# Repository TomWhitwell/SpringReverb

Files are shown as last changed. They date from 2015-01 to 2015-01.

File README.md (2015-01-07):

# Music Thing Spring Reverb  

This repository contains PCB files for the Music Thing Spring Reverb project.  

Full documentation at [Music Thing Modular](http://musicthing.co.uk/modular/?page_id=579)  

Please [report any issues in the Issue Log](https://github.com/TomWhitwell/SpringReverb/issues)

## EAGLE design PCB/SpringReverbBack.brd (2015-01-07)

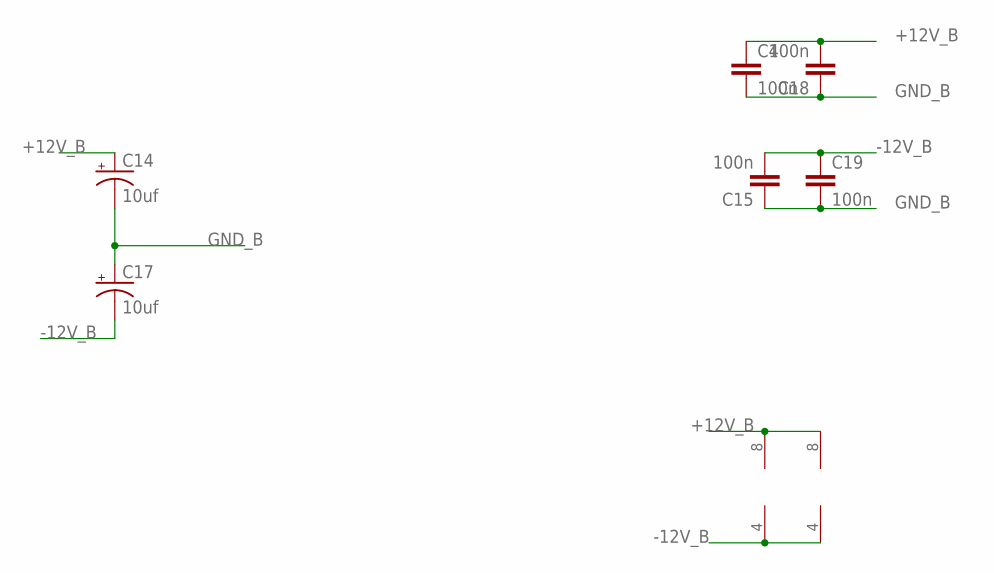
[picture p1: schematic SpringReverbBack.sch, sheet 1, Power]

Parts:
BRICK: TL072; DIL08
C4, C15, C18, C19: 100n; C050-024X044
C14, C17: 10uf; CPOL-RADIAL-10UF-25V
IC4_DRV_RCVR: TL072; DIL08

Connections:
+12V_B: BRICK.8 (V+), C4.1, C14.1 (+), C18.2, IC4_DRV_RCVR.8 (V+); also elsewhere on the board
-12V_B: BRICK.4 (V-), C15.2, C17.2 (-), C19.1, IC4_DRV_RCVR.4 (V-); also elsewhere on the board
GND_B: C4.2, C14.2 (-), C15.1, C17.1 (+), C18.1, C19.2; also elsewhere on the board

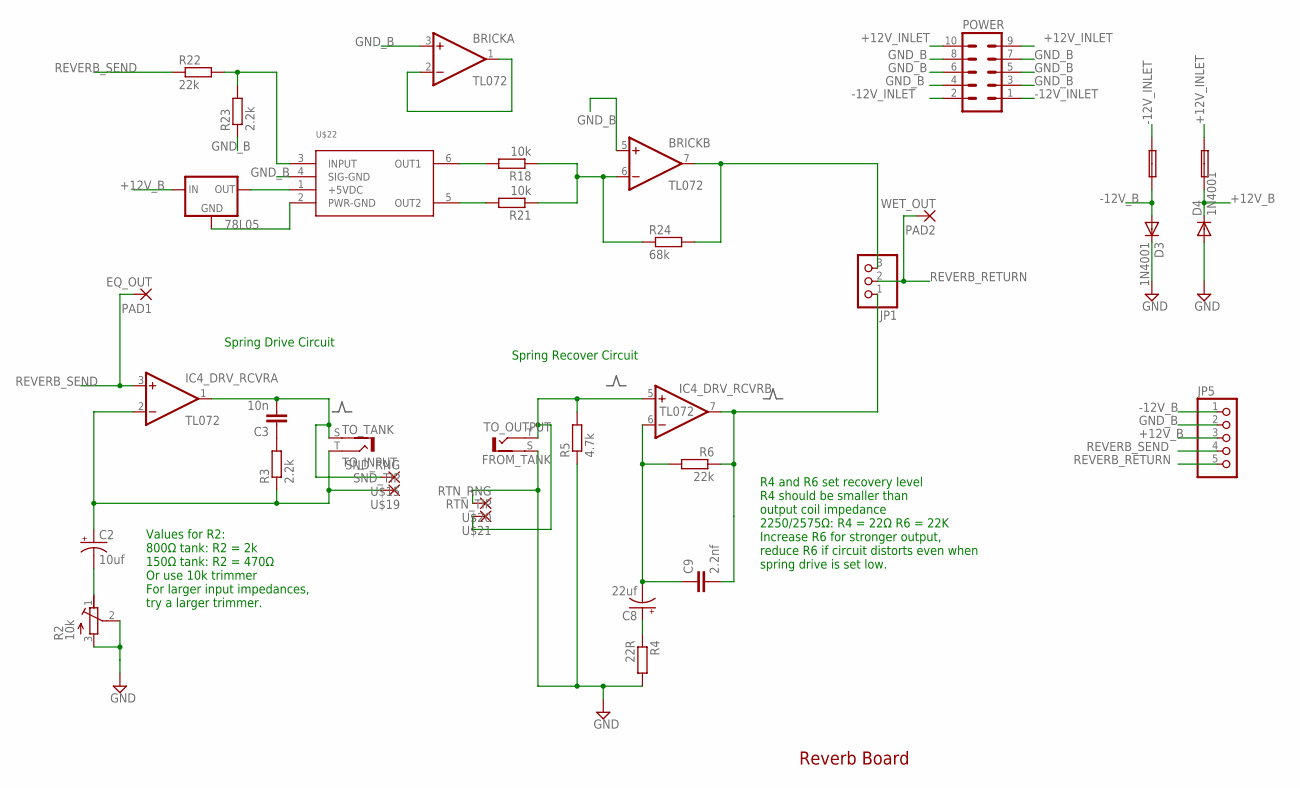
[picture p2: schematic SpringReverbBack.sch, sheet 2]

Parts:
0.1A_FUSE, 0.1A_FUSE_2: FUSE; C050H075X075
78L05: V_REG_78XXTO-92; TO-92
BRICK: TL072; DIL08
C2: 10uf; CPOL-RADIAL-10UF-25V
C3: 10n; C050-024X044
C8: 22uf; CPOL-RADIAL-10UF-25V
C9: 2.2nf; C050-024X044
D3, D4: 1N4001; DO41-10
IC4_DRV_RCVR: TL072; DIL08
JP1: PINHD-1X3; 1X03
JP5: PINHD-1X5; 1X05
PAD1: EQ_OUT; LONG_PAD_1
PAD2: WET_OUT; LONG_PAD_1
POWER: 10_PIN_HEADER; MA05-2
R2: 10k; RTRIMT93YA
R3, R23: 2.2k; 0207/10
R4: 22R; 0207/10
R5: 4.7k; 0207/10
R6, R22: 22k; 0207/10
R18, R21: 10k; 0207/10
R24: 68k; 0207/10
TO_INPUT: TO_TANK; BTOR1
TO_OUTPUT: FROM_TANK; BTOR1
U$15: SND_RNG; LONG_PAD_1
U$19: SND_TIP; LONG_PAD_1
U$20: RTN_RNG; LONG_PAD_1
U$21: RTN_TIP; LONG_PAD_1
U$22: BTDR-2H

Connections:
+12V_B: 0.1A_FUSE_2.1, 78L05.3 (IN), D4.C, JP5.3; also elsewhere on the board
+12V_INLET: 0.1A_FUSE_2.2, POWER.9, POWER.10
-12V_B: 0.1A_FUSE.1, D3.A, JP5.1; also elsewhere on the board
-12V_INLET: 0.1A_FUSE.2, POWER.1, POWER.2
GND_B: BRICK.3 (+IN), BRICK.5 (+IN), D3.C, D4.A, JP5.2, POWER.3, POWER.4, POWER.5, POWER.6, POWER.7, POWER.8, R2.2 (S), R2.3 (E), R4.2, R5.1, R23.1, TO_OUTPUT.S (2), U$20.P$1, U$22.4 (SIG-GND); also elsewhere on the board
unnamed: C2.2 (-), R2.1 (A)
unnamed: C3.1, R3.2
unnamed: C3.2, IC4_DRV_RCVR.1 (OUT), TO_INPUT.S (2), U$15.P$1
unnamed: C2.1 (+), IC4_DRV_RCVR.2 (-IN), R3.1, TO_INPUT.T (1), U$19.P$1
unnamed: IC4_DRV_RCVR.5 (+IN), R5.2, TO_OUTPUT.T (1), U$21.P$1
unnamed: C8.1 (+), R4.1
unnamed: C8.2 (-), C9.1, IC4_DRV_RCVR.6 (-IN), R6.2
unnamed: 78L05.1 (OUT), U$22.1 (+5VDC)
unnamed: R22.2, R23.2, U$22.3 (INPUT)
unnamed: R18.2, U$22.6 (OUT1)
unnamed: R21.2, U$22.5 (OUT2)
unnamed: BRICK.6 (-IN), R18.1, R21.1, R24.1
unnamed: 78L05.2 (GND), U$22.2 (PWR-GND)
unnamed: BRICK.1 (OUT), BRICK.2 (-IN)
unnamed: BRICK.7 (OUT), JP1.3, R24.2
unnamed: C9.2, IC4_DRV_RCVR.7 (OUT), JP1.1, R6.1
REVERB_RETURN: JP1.2, JP5.5, PAD2.P$1
REVERB_SEND: IC4_DRV_RCVR.3 (+IN), JP5.4, PAD1.P$1, R22.1

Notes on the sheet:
Values for R2: 800Ω tank: R2 = 2k 150Ω tank: R2 = 470Ω Or use 10k trimmer For larger input impedances, try a larger trimmer.
Spring Drive Circuit
R4 and R6 set recovery level R4 should be smaller than output coil impedance 2250/2575Ω: R4 = 22Ω R6 = 22K Increase R6 for stronger output, reduce R6 if circuit distorts even when spring drive is set low.
Spring Recover Circuit
Reverb Board

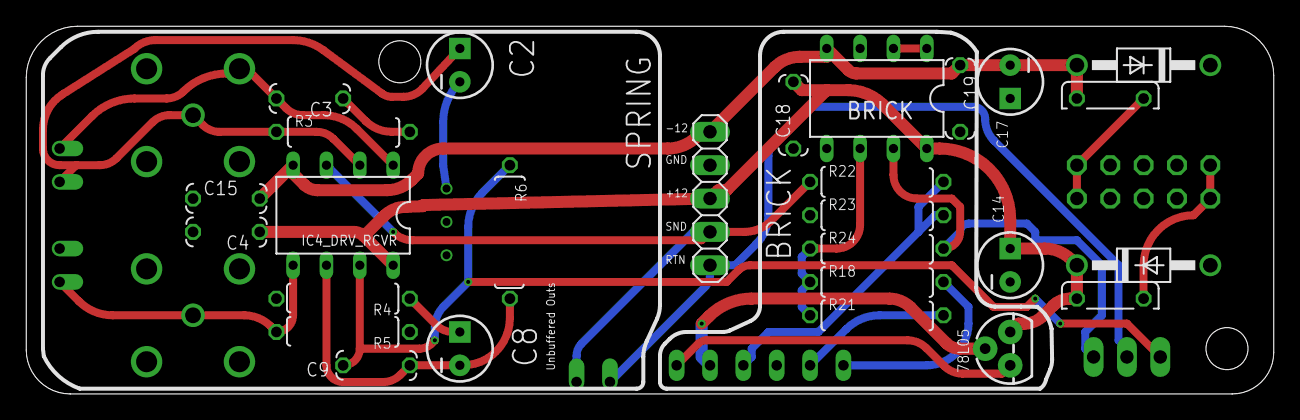
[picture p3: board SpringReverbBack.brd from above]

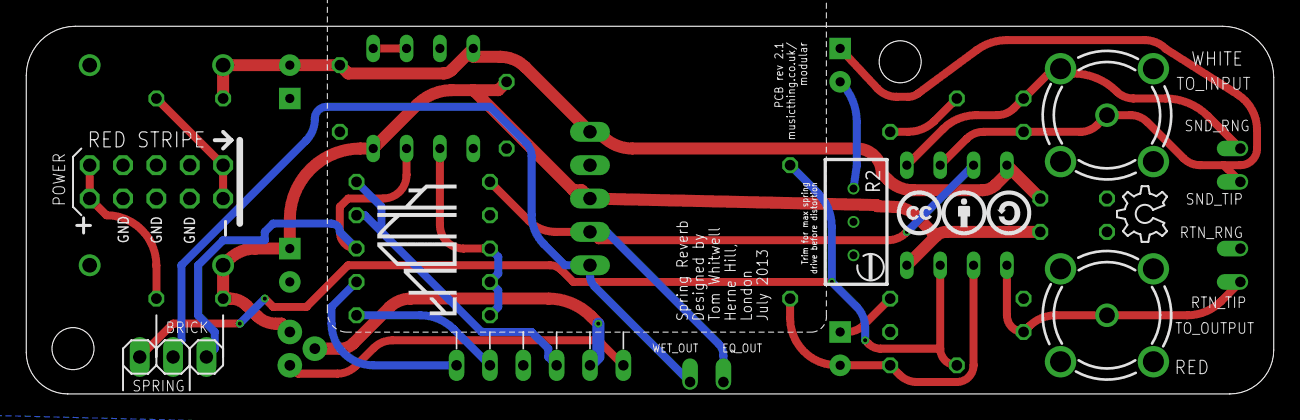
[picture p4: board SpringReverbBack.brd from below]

Board: 4 copper layers, 95.0 x 28.0 mm, 43 parts (10 on the bottom side), 23 nets.

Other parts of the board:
U$1: CC_1CM_SCREENPRINT
U$2: MTM_1CM_KEEPOUT
U$3: OSHW_6X150_NOTEXT
U$4: THONK_1CM_SCREENPRINT

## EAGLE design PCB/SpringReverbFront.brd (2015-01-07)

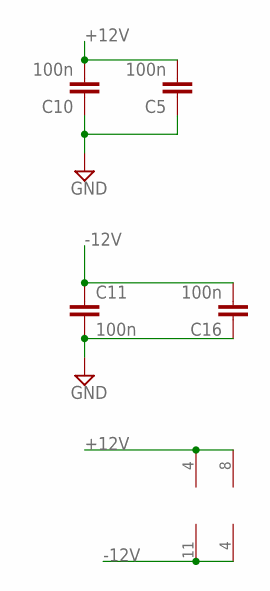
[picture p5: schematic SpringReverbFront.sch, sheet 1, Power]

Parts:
C5, C10, C11, C16: 100n; C050-024X044
IC1: TL074; DIL14
IC2_EQ: NE5532; DIL08

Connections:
+12V: C5.2, C10.2, IC1.4 (V+), IC2_EQ.8 (V+); also elsewhere on the board
-12V: C11.1, C16.2, IC1.11 (V-), IC2_EQ.4 (V-); also elsewhere on the board
GND: C5.1, C10.1, C11.2, C16.1; also elsewhere on the board

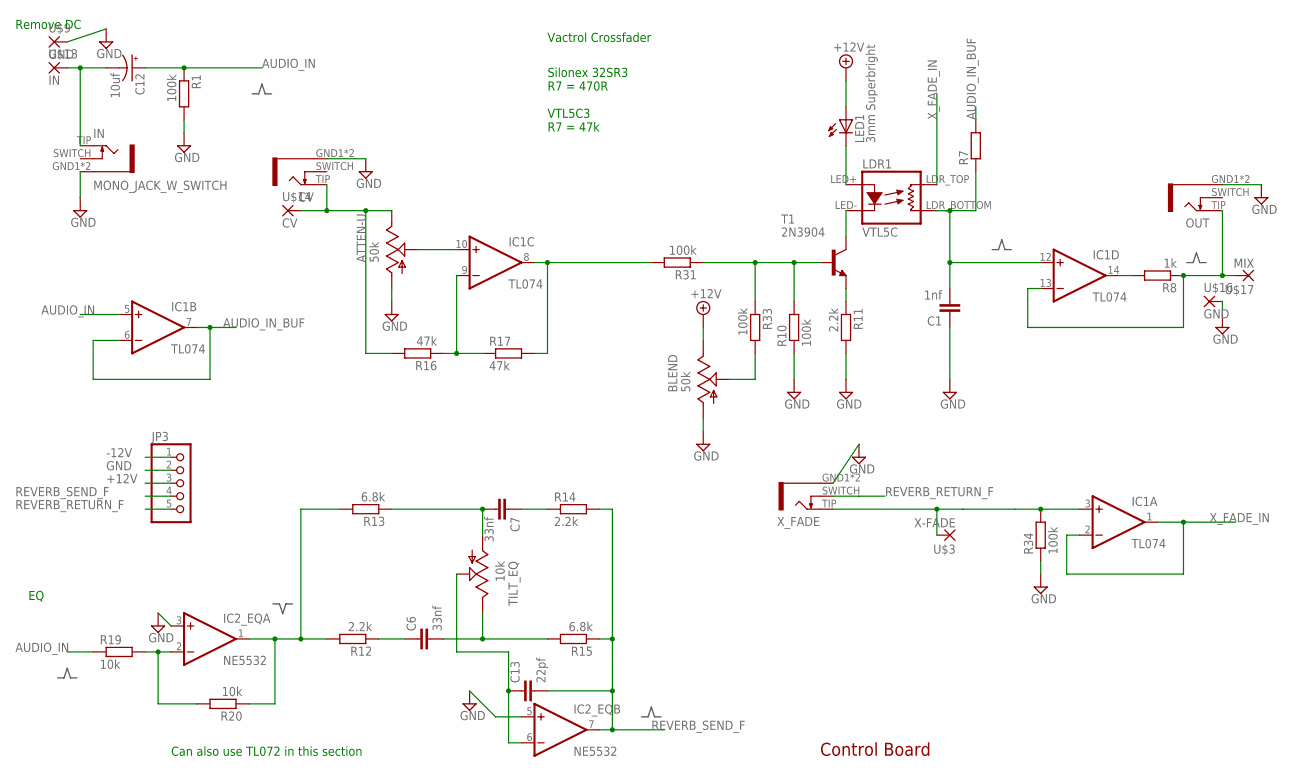
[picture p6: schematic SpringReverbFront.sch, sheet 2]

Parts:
ATTEN-U: 50k; EVUF
BLEND: 50k; EVUF
C1: 1nf; C050-024X044
C6, C7: 33nf; C050-024X044
C12: 10uf; 050_020
C13: 22pf; 050X030_025
CV: MONO_JACK_W_SWITCH; ERTHENVAR
IC1: TL074; DIL14
IC2_EQ: NE5532; DIL08
IN: MONO_JACK_W_SWITCH; ERTHENVAR
JP3: PINHD-1X5; 1X05
LDR1: VTL5C; VACTROL_COMPACT
LED1: 3mm Superbright; LED3MM
OUT: MONO_JACK_W_SWITCH; ERTHENVAR
R1: 100k; VERT-RESISTOR
R7: R-EU_STANDARD_RESISTOR; 0207/10
R8: 1k; 0207/10
R10, R31, R33, R34: 100k; 0207/10
R11, R12, R14: 2.2k; 0207/10
R13, R15: 6.8k; 0207/10
R16, R17: 47k; VERT-RESISTOR
R19: 10k; VERT-RESISTOR
R20: 10k; 0207/10
T1: 2N3904; TO92
TILT_EQ: 10k; EVUF
U$3: X-FADE; LONG_PAD_1
U$9, U$16: GND; LONG_PAD_1
U$13: IN; LONG_PAD_1
U$14: CV; LONG_PAD_1
U$17: MIX; LONG_PAD_1
X_FADE: MONO_JACK_W_SWITCH; ERTHENVAR

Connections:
+12V: BLEND.3 (E), JP3.3, LED1.A; also elsewhere on the board
-12V: JP3.1; also elsewhere on the board
AUDIO_IN: C12.+, IC1.5 (+IN), R1.1, R19.1
AUDIO_IN_BUF: IC1.6 (-IN), IC1.7 (OUT), R7.2
GND: ATTEN-U.1 (A), BLEND.1 (A), C1.1, CV.GND1 (SLEEVE), CV.GND2 (SLEEVE), IC2_EQ.3 (+IN), IC2_EQ.5 (+IN), IN.GND1 (SLEEVE), IN.GND2 (SLEEVE), JP3.2, OUT.GND1 (SLEEVE), OUT.GND2 (SLEEVE), R1.2, R10.1, R11.2, R34.1, U$9.P$1, U$16.P$1, X_FADE.GND1 (SLEEVE), X_FADE.GND2 (SLEEVE); also elsewhere on the board
MIX_OUT_B: IC1.13 (-IN), OUT.TIP, R8.1, U$17.P$1
unnamed: C12.-, IN.TIP, U$13.P$1
unnamed: IC1.3 (+IN), R34.2, U$3.P$1, X_FADE.TIP
unnamed: ATTEN-U.3 (E), CV.TIP, R16.2, U$14.P$1
unnamed: C6.1, R12.1
unnamed: BLEND.2 (S), R33.2
unnamed: IC1.14 (OUT), R8.2
unnamed: C6.2, R15.2, TILT_EQ.3 (E)
unnamed: R11.1, T1.3 (E)
unnamed: C7.2, R13.1, TILT_EQ.1 (A)
unnamed: ATTEN-U.2 (S), IC1.10 (+IN)
unnamed: C7.1, R14.1
unnamed: C13.1, IC2_EQ.6 (-IN), TILT_EQ.2 (S)
unnamed: IC1.9 (-IN), R16.1, R17.1
unnamed: IC2_EQ.2 (-IN), R19.2, R20.2
unnamed: IC1.8 (OUT), R17.2, R31.2
unnamed: LDR1.LED+, LED1.K (C)
unnamed: IC2_EQ.1 (OUT), R12.2, R13.2, R20.1
unnamed: R10.2, R31.1, R33.1, T1.2 (B)
unnamed: LDR1.LED-, T1.1 (C)
REVERB_RETURN_F: JP3.5, X_FADE.SWITCH
REVERB_SEND_F: C13.2, IC2_EQ.7 (OUT), JP3.4, R14.2, R15.1
SUM: C1.2, IC1.12 (+IN), LDR1.LDR_BOTTOM (RES2), R7.1
X_FADE_IN: IC1.1 (OUT), IC1.2 (-IN), LDR1.LDR_TOP (RES1)

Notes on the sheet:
Control Board
Vactrol Crossfader
Silonex 32SR3 R7 = 470R VTL5C3 R7 = 47k
Remove DC
Can also use TL072 in this section

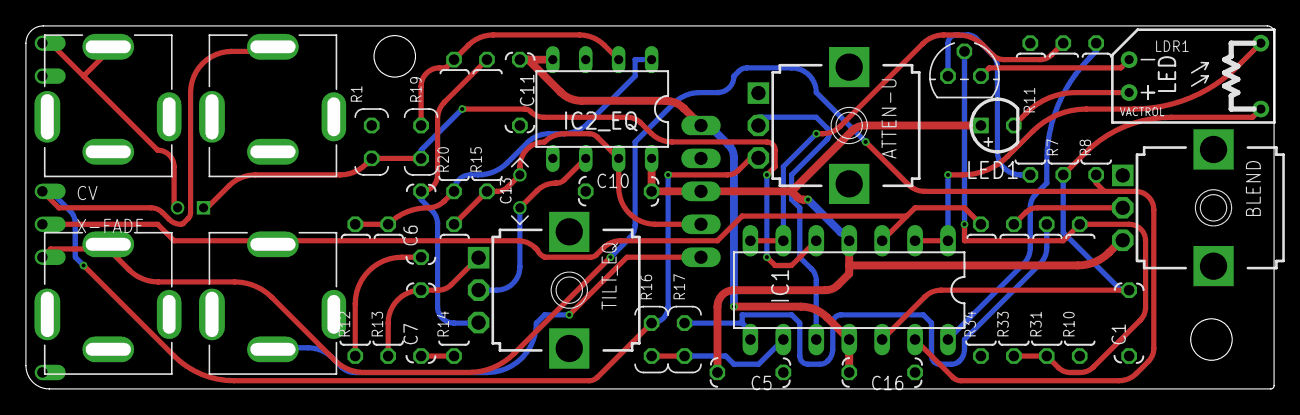
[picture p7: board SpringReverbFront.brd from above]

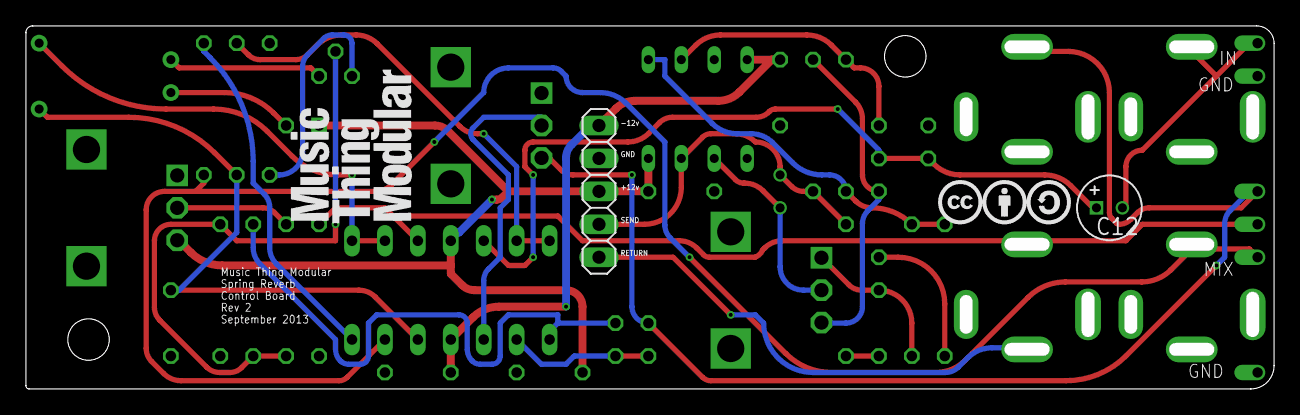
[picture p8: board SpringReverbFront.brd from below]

Board: 4 copper layers, 96.3 x 28.0 mm, 46 parts (4 on the bottom side), 29 nets.

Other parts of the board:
U$8: CC_1CM_SCREENPRINT
U$10: MTM_1CM

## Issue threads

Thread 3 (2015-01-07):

Experiment with extra buffers around x-fade circuit

TomWhitwell, 2015-01-07:
Use unused gate TL072 in Brick section as extra buffer - maybe reduce bleed?

TomWhitwell, 2016-07-10:
This doesn't solve the problem, because it is all buffered already.

BUT removing R34 should help by reducing the output current of the recovery op amp

[simulation](http://lushprojects.com/circuitjs/circuitjs.html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}

Closed 2016-12-07.

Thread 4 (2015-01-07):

Optimise Vactrol LED circuit

TomWhitwell, 2015-01-07:
Check value of R11
Consider giving LED1 indicator its own protection resistor?

TomWhitwell, 2015-01-12:
Testing different LED1 types  with VTL5C3

Results below;

Conclusion: If R7 is correctly set at 47k, the type of LED and value of R11 should make little difference - all of these versions should give good crossfade results, because the 'open' is well below 47k and 'closed' is well above.

Stock: Superbright LED, 2.2k R11

11.7v =  1.3k
6v = 2k
3v = 5.31k
2v = 11.6k
1v = 63k
.5v = unmeasurable

Standard 3mm red LED, 2.2k R11
11.7v = 1.2k
6v = 2.1k
3v = 5.4k
2v = 10.8k
1v = 75k
.5v = unmeasurable

No LED, 2.2k R11
11.7v = 1.09k
6v = 2.2k
3v = 5.5k
2v = 11.6k
1v = 61k
.5v = unmeasurable

Stock LED, 1k R11
11.7v = 750R
6v = 1.3k
3v = 2.9k
2v = 5.4k
1v = 30k
.5v = unmeasurable

TomWhitwell, 2015-01-22:
Copied from http://www.muffwiggler.com/forum/viewtopic.php?p=1766174#1766174

Has changed R11 to 1K instead of 2.2K and has got (for me) a way better crossfading effect. I also changed the TL072 in the spring driver circuit to an 5532, and has a good result driving an Belton RBL3AB3C1B. LLLOOOOOOONG reverb.

TomWhitwell, 2016-07-10:
Conclusion: I don't think this needs to be changed

Closed 2016-07-10.

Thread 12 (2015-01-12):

High pass filtering on reverb send

TomWhitwell, 2015-01-12:
C3 (10n) and R3 (2.2k) form a 7khz low pass filter, stripping all the bass out of the signal

First experiment - short circuit C3 = much clearer reverb (in module with other modifications)

TomWhitwell, 2015-01-14:
Here's the source of that part of the circuit

http://roymal.tripod.com/reverb.htm (caution - noisy spammy page)

The circuit in the schemo is the one he describes

Not sure C3 and R2 form a filter

BUT:
C2 and R2 (the trimmer) definitely form a high pass filter
At 62R (the value in the Mallory note) the cutoff is 256hz - to strip the bass out of the spring in a guitar amp
At my experimental value for 2k, the cutoff is 8hz
At 10k - max possible value, cutoff is 1.6hz

So probably NOT the problem?

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

TomWhitwell, 2016-07-10:
From Roymal:
A frequency between 5 kHz and 10 kHz is appropriate for a guitar amplifier. The 8DB2C1B tank has an inductance of about 44 mH; the test circuit uses a 0.01 m H capacitor to produce a break frequency of about 7.6 kHz.

SO... we want higher response - Make C3 = 5nf = 14.5khz

Closed 2016-12-07.

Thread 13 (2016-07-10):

various ideas

TomWhitwell, 2016-07-10:
Quick version:
- Same front panel layout - very minor build doc changes
- FRONT PCB: Github - Move to Thonkiconn sockets? (probably also fixes Github - Move solder points from under sockets)
- FRONT PCB: Github - Improve ground plane (make it less fragile to damage)
- FRONT PCB: Github - Remove C1? (or change silkscreen I currently ship kits with 100pF here)

Medium version:
- Slightly different panel layout
- Put Red flathead LED up top like Turing and Radio
- Move to MXR knob to match Turing Mk II
- Have jack sockets line up with Turing
- Some kind of simple line graphics like Turing? (maybe circles radiating from centre of MXR knob?)
- Consider moving to tall trimmers on CV and Tilt to reduce kit cost.

Rehaul:
- 2hp wider panel
- Phonos on front and back - one panel solution not two3
- Two switchable bricks, short and long (i dunno how different the bricks are though...)
- dedicated wet out
- Incorporate Finlays unreleased expander design, feedback circuit with
- inversion switch
- feedback send/return
- Clip LED

Closed 2016-12-11.

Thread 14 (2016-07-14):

Rev 2 - Attenuverter on 2nd input

TomWhitwell, 2016-07-14:
Gain of 1.5x to allow for boost

[This schematic](http://lushprojects.com/circuitjs/circuitjs.html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)

Closed 2016-12-11.

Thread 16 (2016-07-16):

Match Turing Mk2

TomWhitwell, 2016-07-16:
Turing front

Bottom row of sockets 250
2nd row of sockets 825
main knob 3050
switch knob 1800
led row 4140

Radio Music Sockets

250 - 175
250 - 575
825 - 175
825 - 575

So next column should be
250 - 975
825 - 975

Closed 2016-12-11.

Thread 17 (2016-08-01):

between panel connection notes

TomWhitwell, 2016-08-01:
PCB size 107 x 29.5

A socket = JP1
Position 1850 100
Angle 180
Mirror = true  (i.e. on back of front board)
SparkFun-Connectors 1X06
Pin 1 / MixF is closest to sockets at base of board

B socket = JP2
Position 3600 100
Angle 180
Mirror = true
Pin 1 VAC_AN_F closest to sockets at base of board

Mounting hole
Positon 3250 1037.5
Angle 0
Mounting Hole from MTM LIbrary

A1 MIX_F = MIX_B - By mix socket bottom row far right
A2 WET_F = WET_B - wet socket, bottom middle, also solder point and feeback socket, top left
A3 XFADE_F = XFADE_B -  - by xfade socket middle top row
A4 REVERB_RETURN_F = REVERB_RETURN_B - by xfade socket middle top row
A5 REVERB_SEND_F = REVERB_SEND_B - output pin on 5532
A6 DRY_F = DRY_B - Output pin on tl074, input pin on 5532

B1 VAC_AN_F = VAC_AN_B - TL074 and LED
B2 VAC_CA_F = VAC_CA_B - TL074 and LED
B3 TRIM_F  = TRIM_B - By trimmer
B4 +12V = +12V_B - op amps
B5 -12V = +12V_B - op amps
B6 GND = GND_B

Closed 2016-12-11.

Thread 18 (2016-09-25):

Between panel board power connection error

TomWhitwell, 2016-09-25:
+12v and -12v swapped on rev3 pcb

Back:
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

FRONT:
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

Closed 2016-12-11.

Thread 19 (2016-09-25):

LED Driver wrong

TomWhitwell, 2016-09-25:
LED Driver not working at all
Doesn't work yet with LEDs in the feedback loop

[simulation](http://lushprojects.com/circuitjs/circuitjs.html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)

Closed 2016-12-11.

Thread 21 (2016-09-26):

CV attenuverter issue

TomWhitwell, 2016-09-26:
Currently a +5v input gives -0.5v -> +5v range (same with -5v)
Maybe build rather than schematic?

Closed 2016-12-11.

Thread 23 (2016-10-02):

Holes for spring module are very tight

TomWhitwell, 2016-10-02:

Closed 2016-12-11.

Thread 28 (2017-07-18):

Replace 'proto' markings on PCBs

TomWhitwell, 2017-07-18:

Closed 2017-07-18.

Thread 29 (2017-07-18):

jp102 is on the wrong side on main pcb

TomWhitwell, 2017-07-18:

Closed 2017-07-18.

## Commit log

2015-01-07 Upload files as manufactured rev 2.1
    [SpringReverbBack.brd, SpringReverbBack.sch, SpringReverbFront.brd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]
2015-01-07 Updated to Eagle 7.2
    [SpringReverbBack.brd, SpringReverbBack.sch, SpringReverbFront.brd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]

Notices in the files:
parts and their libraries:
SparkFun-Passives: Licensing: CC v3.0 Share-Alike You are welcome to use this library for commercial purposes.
